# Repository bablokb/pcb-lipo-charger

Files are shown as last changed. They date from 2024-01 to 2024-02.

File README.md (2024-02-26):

A small LiPo Charger using the MCP73831 and the XB6166IS
========================================================

Here are the KiCAD (v6) design-files for a small LiPo charger.
The charger supports charging with an attached load.

The charging IC is the MCP73831T-2ACI/OT. For details, see the
schematic.

For battery protection, the XB6166IS from XySemi is used.
Overcurrent detection kicks in at about 900mA, so this is
not a charger for high loads.

The charge curve below shows both phases: constant current at
the beginning and constant voltage after reaching the cutoff
voltage. Charge termination is at 15mA.

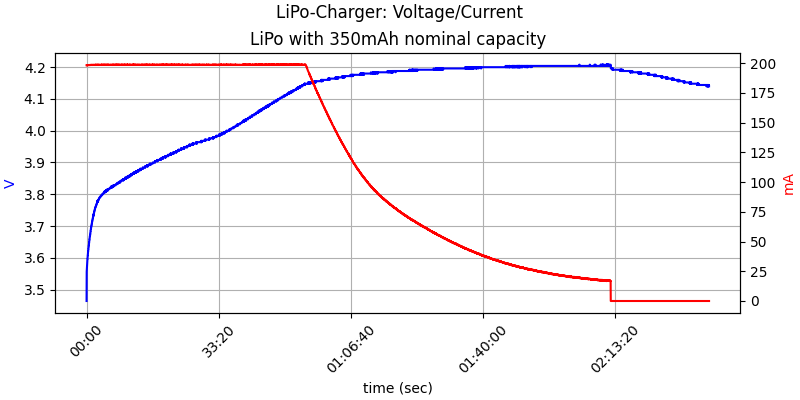
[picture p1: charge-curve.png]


Schematic
---------

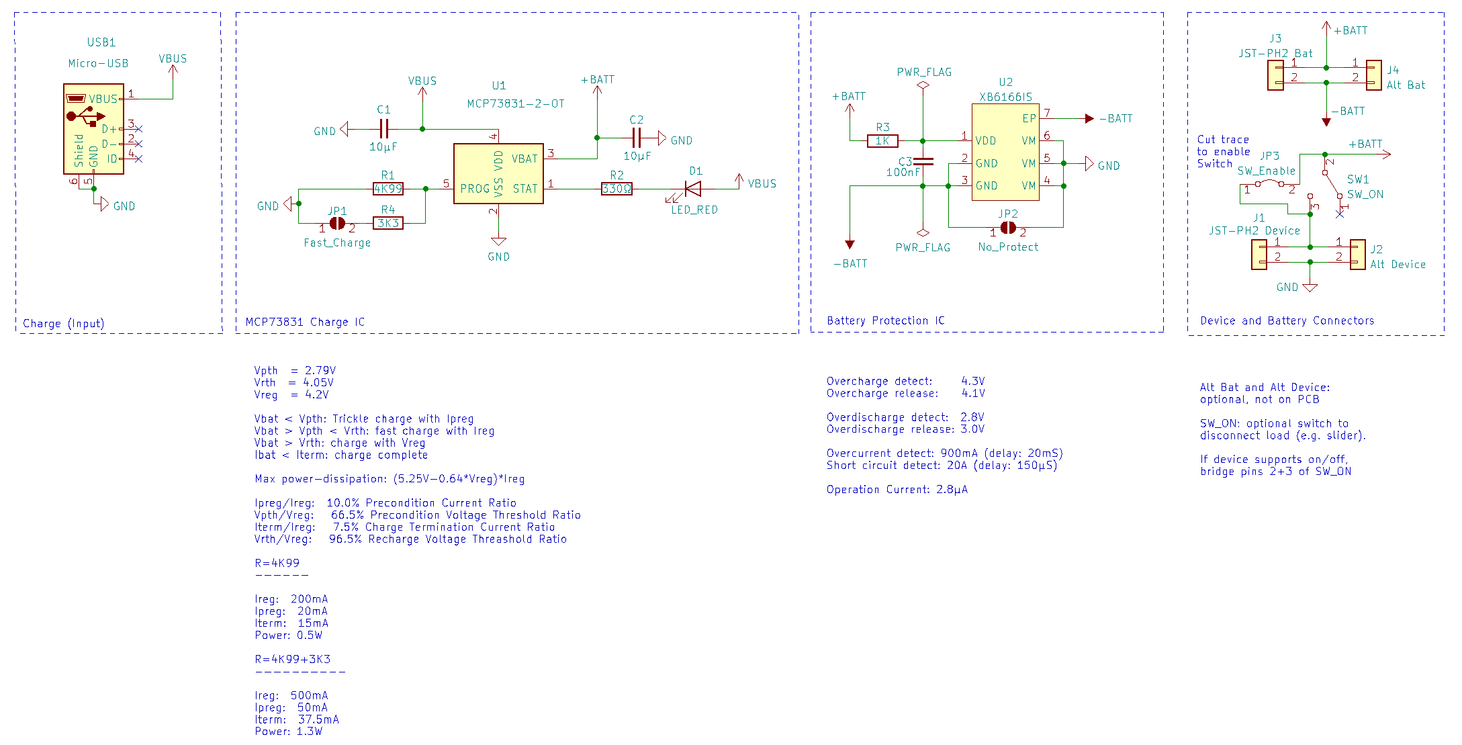
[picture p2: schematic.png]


Layout
------

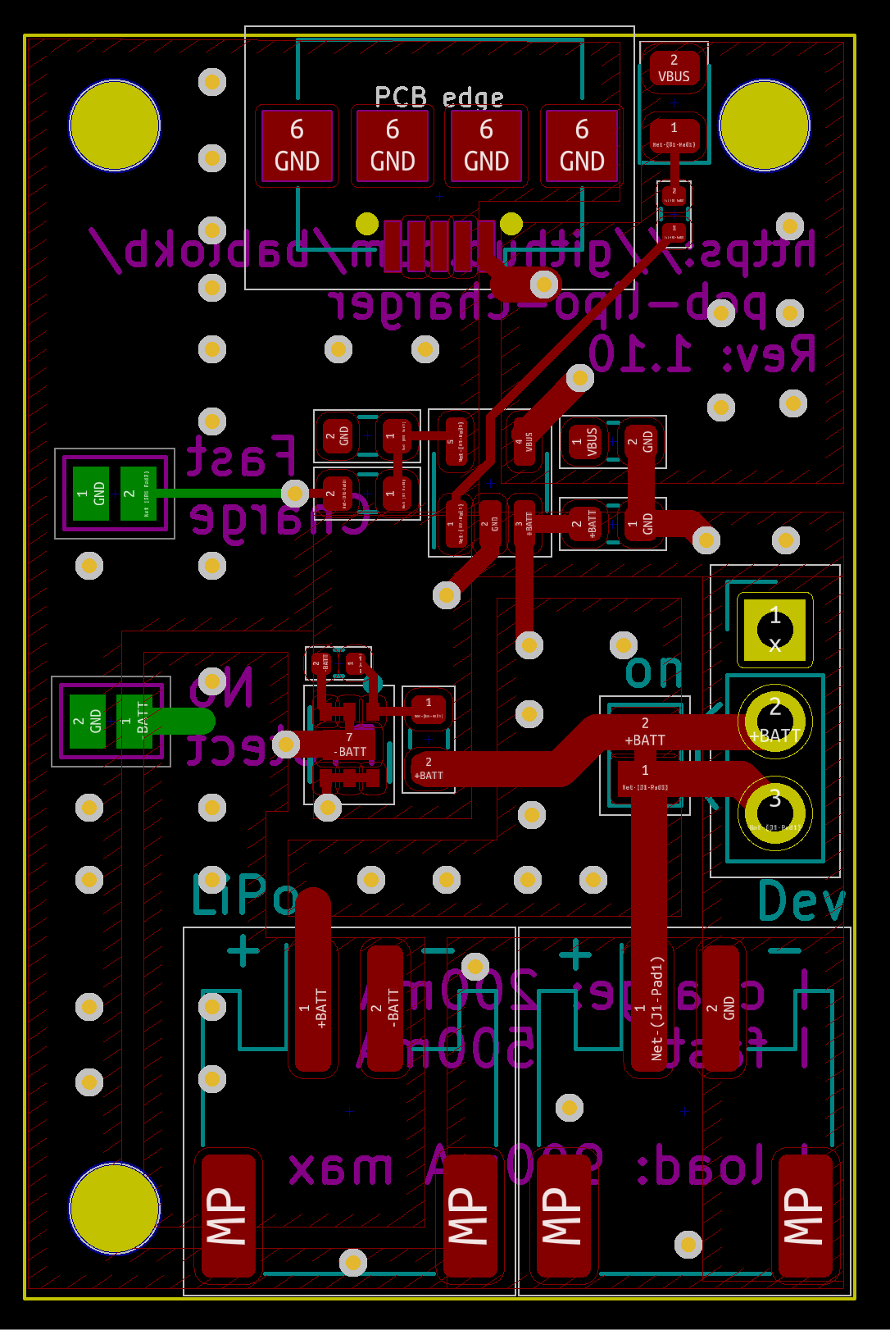
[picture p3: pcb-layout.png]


3D-Views
--------

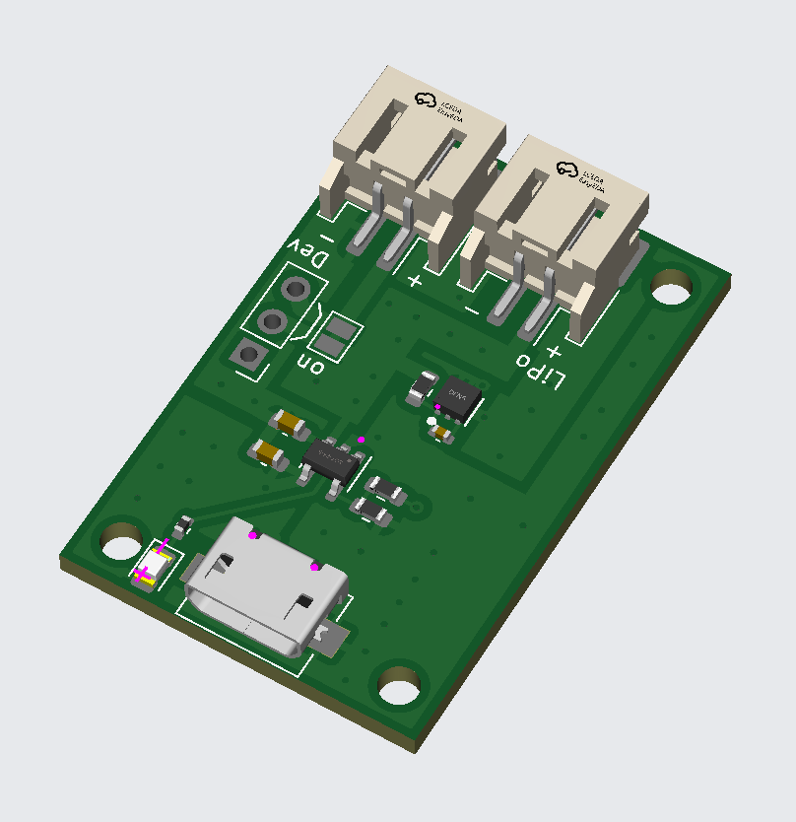
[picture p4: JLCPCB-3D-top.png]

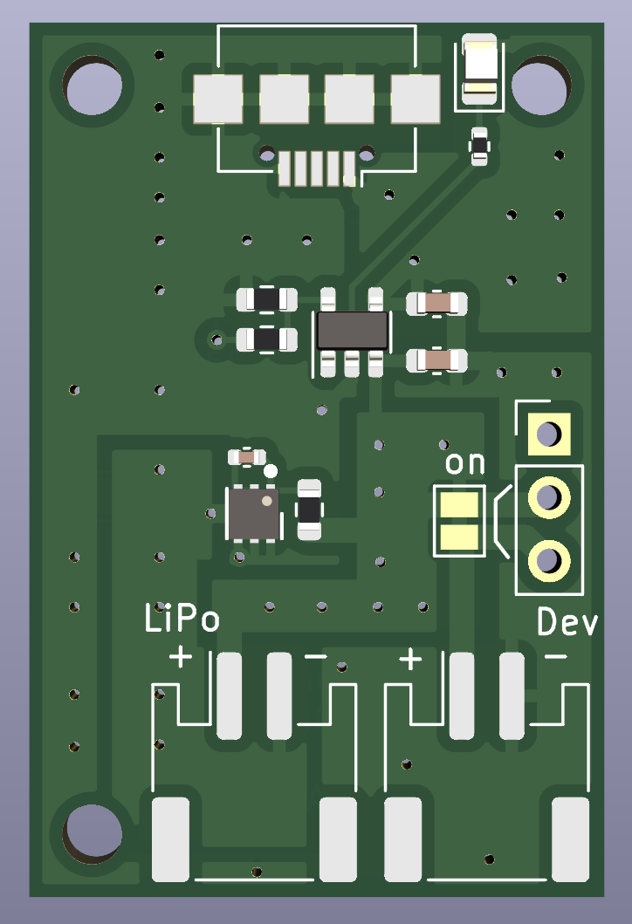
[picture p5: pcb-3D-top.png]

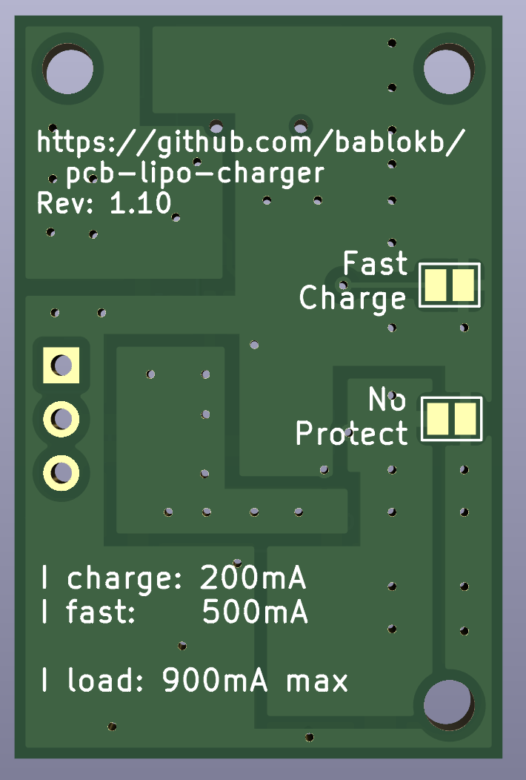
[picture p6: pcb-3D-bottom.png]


License
-------

[![CC BY-SA 4.0][cc-by-sa-shield]][cc-by-sa]

This work is licensed under a
[Creative Commons Attribution-ShareAlike 4.0 International
License][cc-by-sa].

[][cc-by-sa]

[cc-by-sa]: http://creativecommons.org/licenses/by-sa/4.0/
[cc-by-sa-image]: https://licensebuttons.net/l/by-sa/4.0/88x31.png
[cc-by-sa-shield]:
https://img.shields.io/badge/License-CC%20BY--SA%204.0-lightgrey.svg

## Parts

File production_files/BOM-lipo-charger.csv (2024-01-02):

Comment | Designator | Footprint | LCSC
100nF | C3 | C_0402_1005Metric | C1525
10µF | C1,C2 | C_0603_1608Metric | C19702
1K | R3 | R_0603_1608Metric | C21190
3K3 | R4 | R_0603_1608Metric | C22978
4K99 | R1 | R_0603_1608Metric | C23046
330Ω | R2 | R_0402_1005Metric | C25104
JST-PH2 Device | J1,J3 | JST_PH_S2B-PH-SM4-TB_1x02-1MP_P2.00mm_Horizontal | C295747
Micro-USB | USB1 | USB_Micro-B_JLCPCB_40942 | C40942
MCP73831-2-OT | U1 | SOT-23-5 | C424093
LED_RED | D1 | LED_0805_2012Metric | C84256
XB6166IS | U2 | DFN-2x2mm-0.75 | C94310

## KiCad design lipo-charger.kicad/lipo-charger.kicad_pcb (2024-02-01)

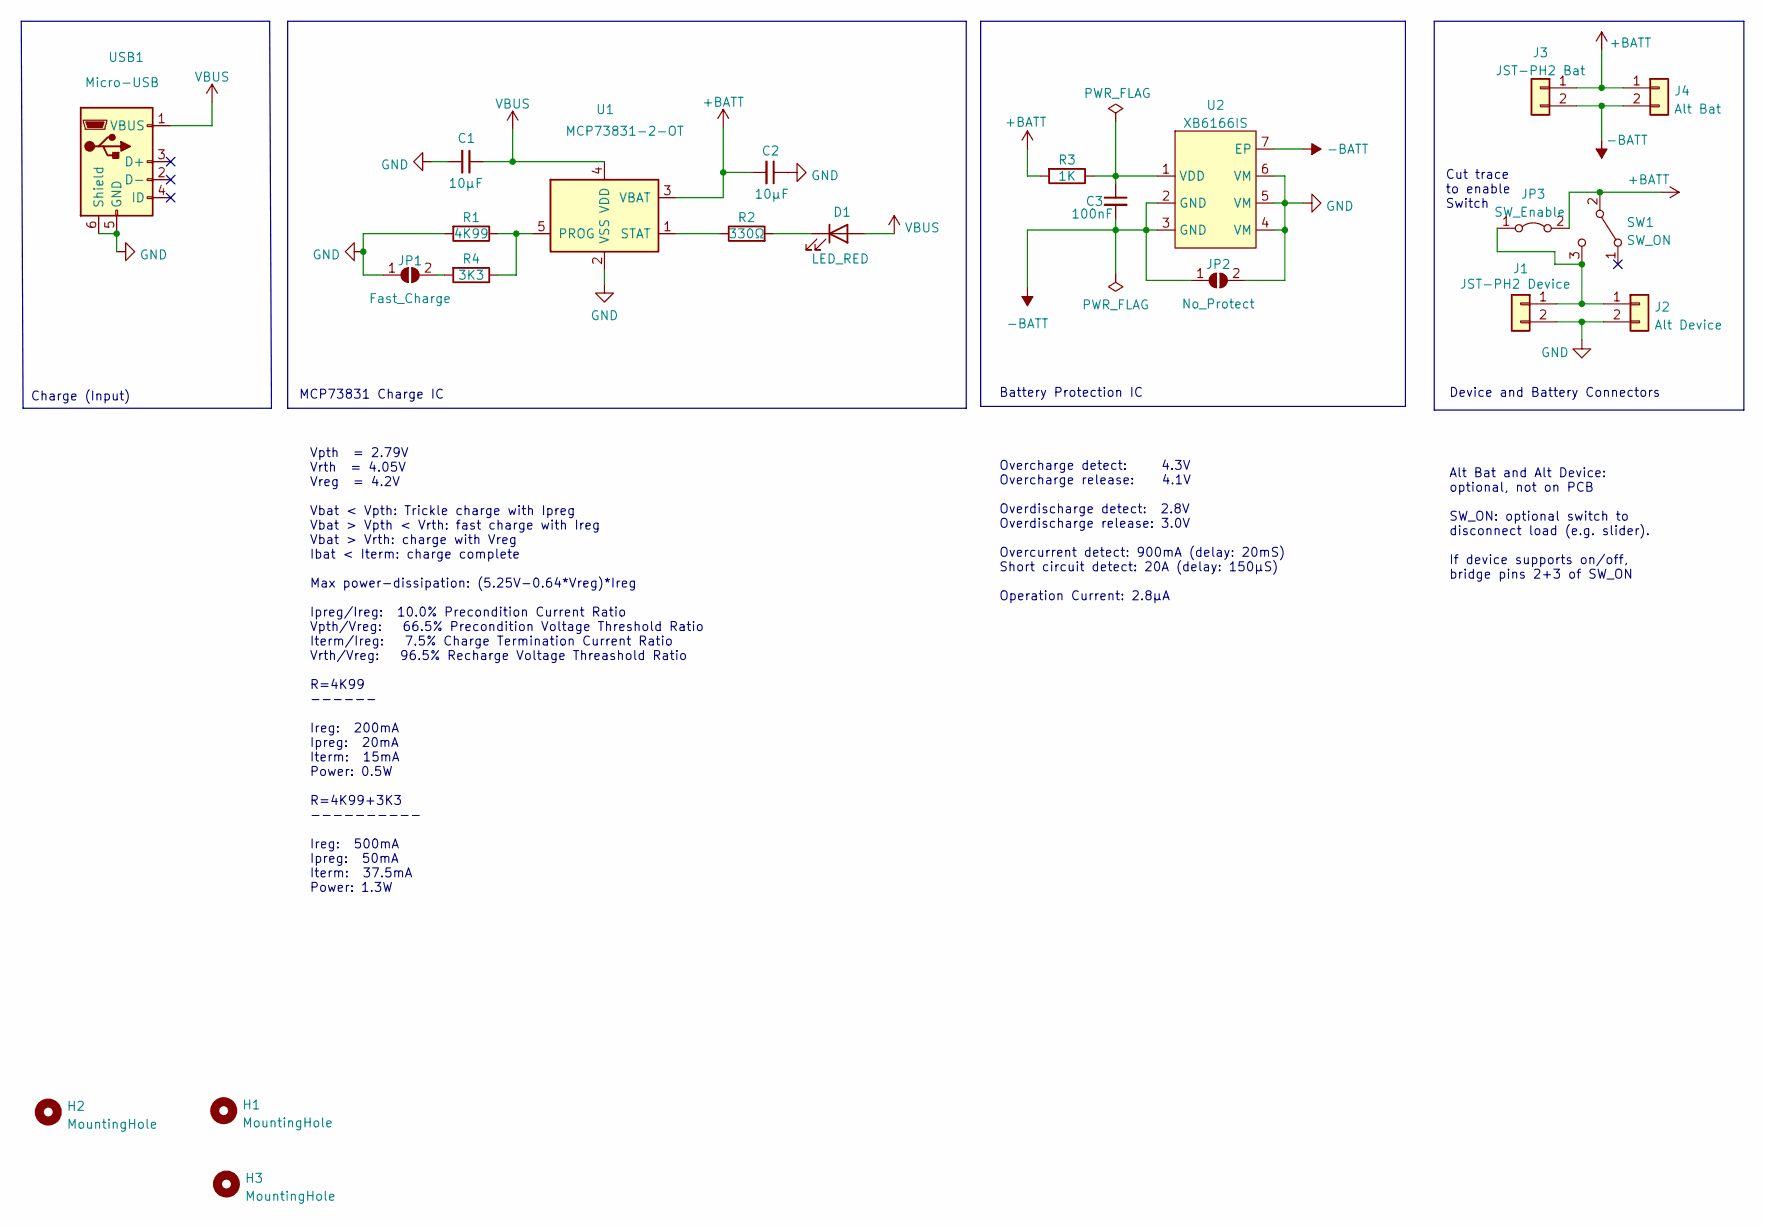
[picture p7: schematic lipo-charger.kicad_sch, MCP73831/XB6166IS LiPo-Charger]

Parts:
C1, C2: 10µF; C_0603_1608Metric; LCSC C19702
C3: 100nF; C_0402_1005Metric; LCSC C1525
D1: LED_RED; LED_0805_2012Metric; LCSC C84256
H1, H2, H3: MountingHole; MountingHole_2.4mm_M2
J1: JST-PH2 Device; JST_PH_S2B-PH-SM4-TB_1x02-1MP_P2.00mm_Horizontal; LCSC C295747
J2: Alt Device; PinHeader_1x02_P2.54mm_Vertical
J3: JST-PH2 Bat; JST_PH_S2B-PH-SM4-TB_1x02-1MP_P2.00mm_Horizontal; LCSC C295747
J4: Alt Bat; PinHeader_1x02_P2.54mm_Vertical
JP1: Fast_Charge; SolderJumper-2_P1.3mm_Open_Pad1.0x1.5mm
JP2: No_Protect; SolderJumper-2_P1.3mm_Open_Pad1.0x1.5mm
JP3: SW_Enable; SolderJumper-2_P1.3mm_Bridged_Pad1.0x1.5mm
R1: 4K99; R_0603_1608Metric; LCSC C23046
R2: 330Ω; R_0402_1005Metric; LCSC C25104
R3: 1K; R_0603_1608Metric; LCSC C21190
R4: 3K3; R_0603_1608Metric; LCSC C22978
SW1: SW_ON; PinHeader_1x03_P2.54mm_Vertical
U1: MCP73831-2-OT; SOT-23-5; LCSC C424093
U2: XB6166IS; DFN-2x2mm-0.75; LCSC C94310
USB1: Micro-USB; USB_Micro-B_JLCPCB_40942; LCSC C40942

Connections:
+BATT: C2.2, J3.1, J4.1, JP3.2 (B), R3.2, SW1.2 (B), U1.3 (VBAT)
-BATT: C3.2, J3.2, J4.2, JP2.1 (A), U2.2 (GND), U2.3 (GND), U2.7 (EP)
GND: C1.2, C2.1, J1.2, J2.2, JP1.1 (A), JP2.2 (B), R1.2, U1.2 (VSS), U2.4 (VM), U2.5 (VM), U2.6 (VM), USB1.5 (GND), USB1.6 (Shield)
unnamed: C3.1, R3.1, U2.1 (VDD)
unnamed: D1.1 (K), R2.2
unnamed: J1.1, J2.1, JP3.1 (A), SW1.3 (C)
unnamed: JP1.2 (B), R4.2
unnamed: R1.1, R4.1, U1.5 (PROG)
unnamed: R2.1, U1.1 (STAT)
VBUS: C1.1, D1.2 (A), U1.4 (VDD), USB1.1 (VBUS)

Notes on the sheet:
Vpth = 2.79V Vrth = 4.05V Vreg = 4.2V Vbat < Vpth: Trickle charge with Ipreg Vbat > Vpth < Vrth: fast charge with Ireg Vbat > Vrth: charge with Vreg Ibat < Iterm: charge complete Max power-dissipation: (5.25V-0.64*Vreg)*Ireg Ipreg/Ireg: 10.0% Precondition Current Ratio Vpth/Vreg: 66.5% Precondition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
Battery Protection IC
Overcharge detect: 4.3V Overcharge release: 4.1V Overdischarge detect: 2.8V Overdischarge release: 3.0V Overcurrent detect: 900mA (delay: 20mS) Short circuit detect: 20A (delay: 150µS) Operation Current: 2.8µA
Device and Battery Connectors
Alt Bat and Alt Device: optional, not on PCB SW_ON: optional switch to disconnect load (e.g. slider). If device supports on/off, bridge pins 2+3 of SW_ON
Charge (Input)
Cut trace to enable Switch
MCP73831 Charge IC

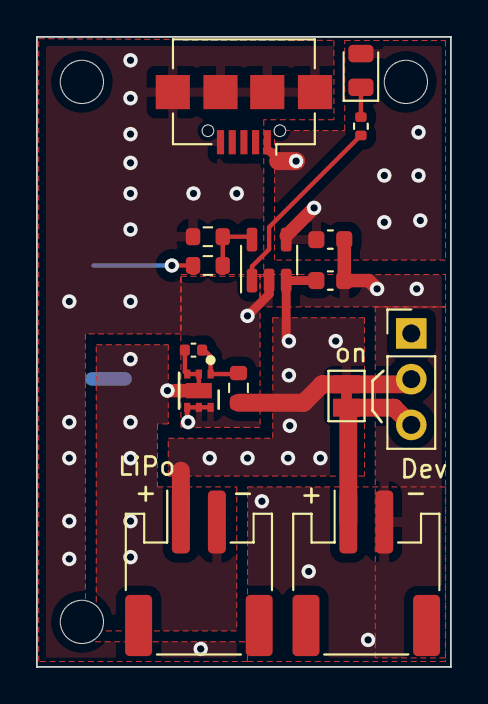
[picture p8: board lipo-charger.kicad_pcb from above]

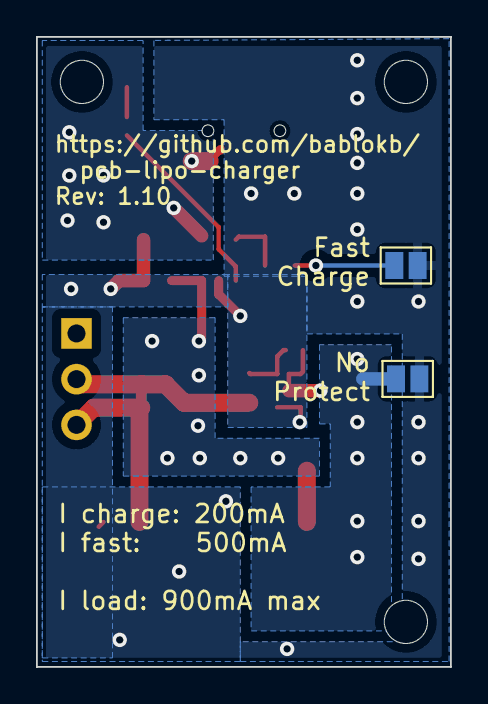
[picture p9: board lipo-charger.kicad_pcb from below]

Board: 2 copper layers, 23.0 x 35.0 mm, 20 parts (2 on the bottom side), 10 nets.

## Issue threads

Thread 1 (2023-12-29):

Behavior after overdischarge

tomek-szczesny, 2023-12-29:
Hey @bablokb,
I looked briefly at your design and just one question:
I understand that overdischarge protection is supposed to shut down the downstream device when the battery is depleted.
Since battery protector has hysteresis, and the battery must be slightly charged up to release the protection latch, will recharging work in this scenario?

If you also think there might be a problem, consider mounting ~100R resistor on JP2, which will allow bypassing the protection chip with small precondition current.

bablokb, 2023-12-30:
Hi Tom,
thanks for checking and the hint with the resistor. The datasheet of the XB6166IS claims that it will allow charging even of fully depleted batteries ("0V Battery Charging Function"). I don't plan to do discharge that far, the chip should stop at 2.8V. But I will test as soon as I have the first batch.

Anyhow, I had a hard time finding a suitable all-in-one chip. Many chips from XySemi have a over-discharge limit of 2.4V, which seems very low to me.

tomek-szczesny, 2023-12-30:
Excellent, I was fully expecting you to have foreseen this corner case. :)

Battery protection chips are meant to be the protection, which means it shouldn't ever be triggered by normal operation of the device. They are only to prevent battery explosion or fume discharge if the device or charger fails.
This is why they are produced as separate chips, to be included in battery packs.
And also this is why their overvoltage and undervoltage levels are sightly wider than for normal operation. 2.4V is a reasonable protection for a battery that is nominally depleted at 2.5V.

Your device should monitor its own voltage and shut down itself when it gets too low.
For example, there are cheap SOT-23 chips, "reset controllers" or something like that, that essentially pull pin low when voltage is above or below certain fixed threshold. This may be used to cut off input voltage of the device, or force it into reset state, when voltage gets too low.

But that's what "good practices" look like. As long as you keep an eye on your device you should be fine.

bablokb, 2023-12-30:
This is a prototype for the target device. That device has an RTC which stops working at about 3V (i.e. when the LiPo level drops below the voltage of the backup-coincell). The coincell then just keeps the time, but the RTC does no longer wakeup the device. So I hope this keeps me away from the actual threshold.

tomek-szczesny, 2023-12-30:
Ah, if this board is dedicated to a device with reasonable battery draining scheme then I see no further objections.
If this is the case, indeed the protection chip should only be triggered outside design parameters.
My remarks would be relevant only if it was meant to be a universal module.

Thanks for sharing your reasoning. :)

I think this issue can be closed :D

Closed 2023-12-30.

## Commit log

2023-12-30 Rev 0.91: remove alternative connectors for LiPo and device
    [lipo-charger.kicad_pcb, lipo-charger.kicad_sch]
2023-12-30 Rev: 0.92: add (optional) switch for load
    [lipo-charger.kicad_pcb, lipo-charger.kicad_sch]
2024-01-02 Rev. 0.93 (added switch for load) - in production
    [BOM-lipo-charger.csv, lipo-charger.kicad_pcb, lipo-charger.kicad_sch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]
2024-02-01 Rev 1.10: added 'always-on' trace-jumper
    [lipo-charger.kicad_pcb, lipo-charger.kicad_sch]
2024-02-26 added charge curve
